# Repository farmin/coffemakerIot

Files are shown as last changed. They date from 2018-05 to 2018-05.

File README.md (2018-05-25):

# mokkamaster-autoff-iot

Simple project to demonstrate howto use Wifi and mqtt on a esp32 using the Arduino
framework. The project includes a custom sensor board that comunicates to host via
i2c. The sensor is ment to provide useful feedback from a MokkaMaster or similar type
of coffe machine.

## Installing

This project uses [Platformio](https://platformio.org/) as build platform. It installs from
terminal by typing in the following commands:
```
pip install platformio
cd ../coffemakerIot
platformio run
platformio run -t upload

```
### Prerequisites

You probably need pip to install platfomrio. you also need to add yourself to the dialout 
group.

```
python pip
sudo adduser $USER dialout
```

## Known bugs

I2c Bus dropouts, could be hw fault.
Wifi dropouts

# Investigate this
[E][ssl_client.cpp:32] handle_error(): UNKNOWN ERROR CODE (004E)
[E][ssl_client.cpp:34] handle_error(): MbedTLS message code: -78
[E][ssl_client.cpp:84] start_ssl_client(): Connect to Server failed!
[E][WiFiClientSecure.cpp:108] connect(): lwip_connect_r: 113
[E][ssl_client.cpp:84] start_ssl_client(): Connect to Server failed!
[E][WiFiClientSecure.cpp:108] connect(): lwip_connect_r: 113
[E][ssl_client.cpp:84] start_ssl_client(): Connect to Server failed!
[E][WiFiClientSecure.cpp:108] connect(): lwip_connect_r: 113

## Built With

* [Arduino](https://www.arduino.cc/) - Arduino enviroment
* [ArduinoJson](https://arduinojson.org/) - Json library
* [arduino-mqtt](https://github.com/256dpi/arduino-mqtt) - Mqtt framework
* [Adafruit-sensors](https://www.adafruit.com/) - libraries for ADS1X15 and MLX90614 sensors

## Authors

* **Armin Bårdseth** - *Initial work*

## License

This project is licensed under the MIT License - see the [LICENSE.md](LICENSE.md) file for details

## Acknowledgments

* Hat tip to anyone who's code was used
* Inspiration
* etc

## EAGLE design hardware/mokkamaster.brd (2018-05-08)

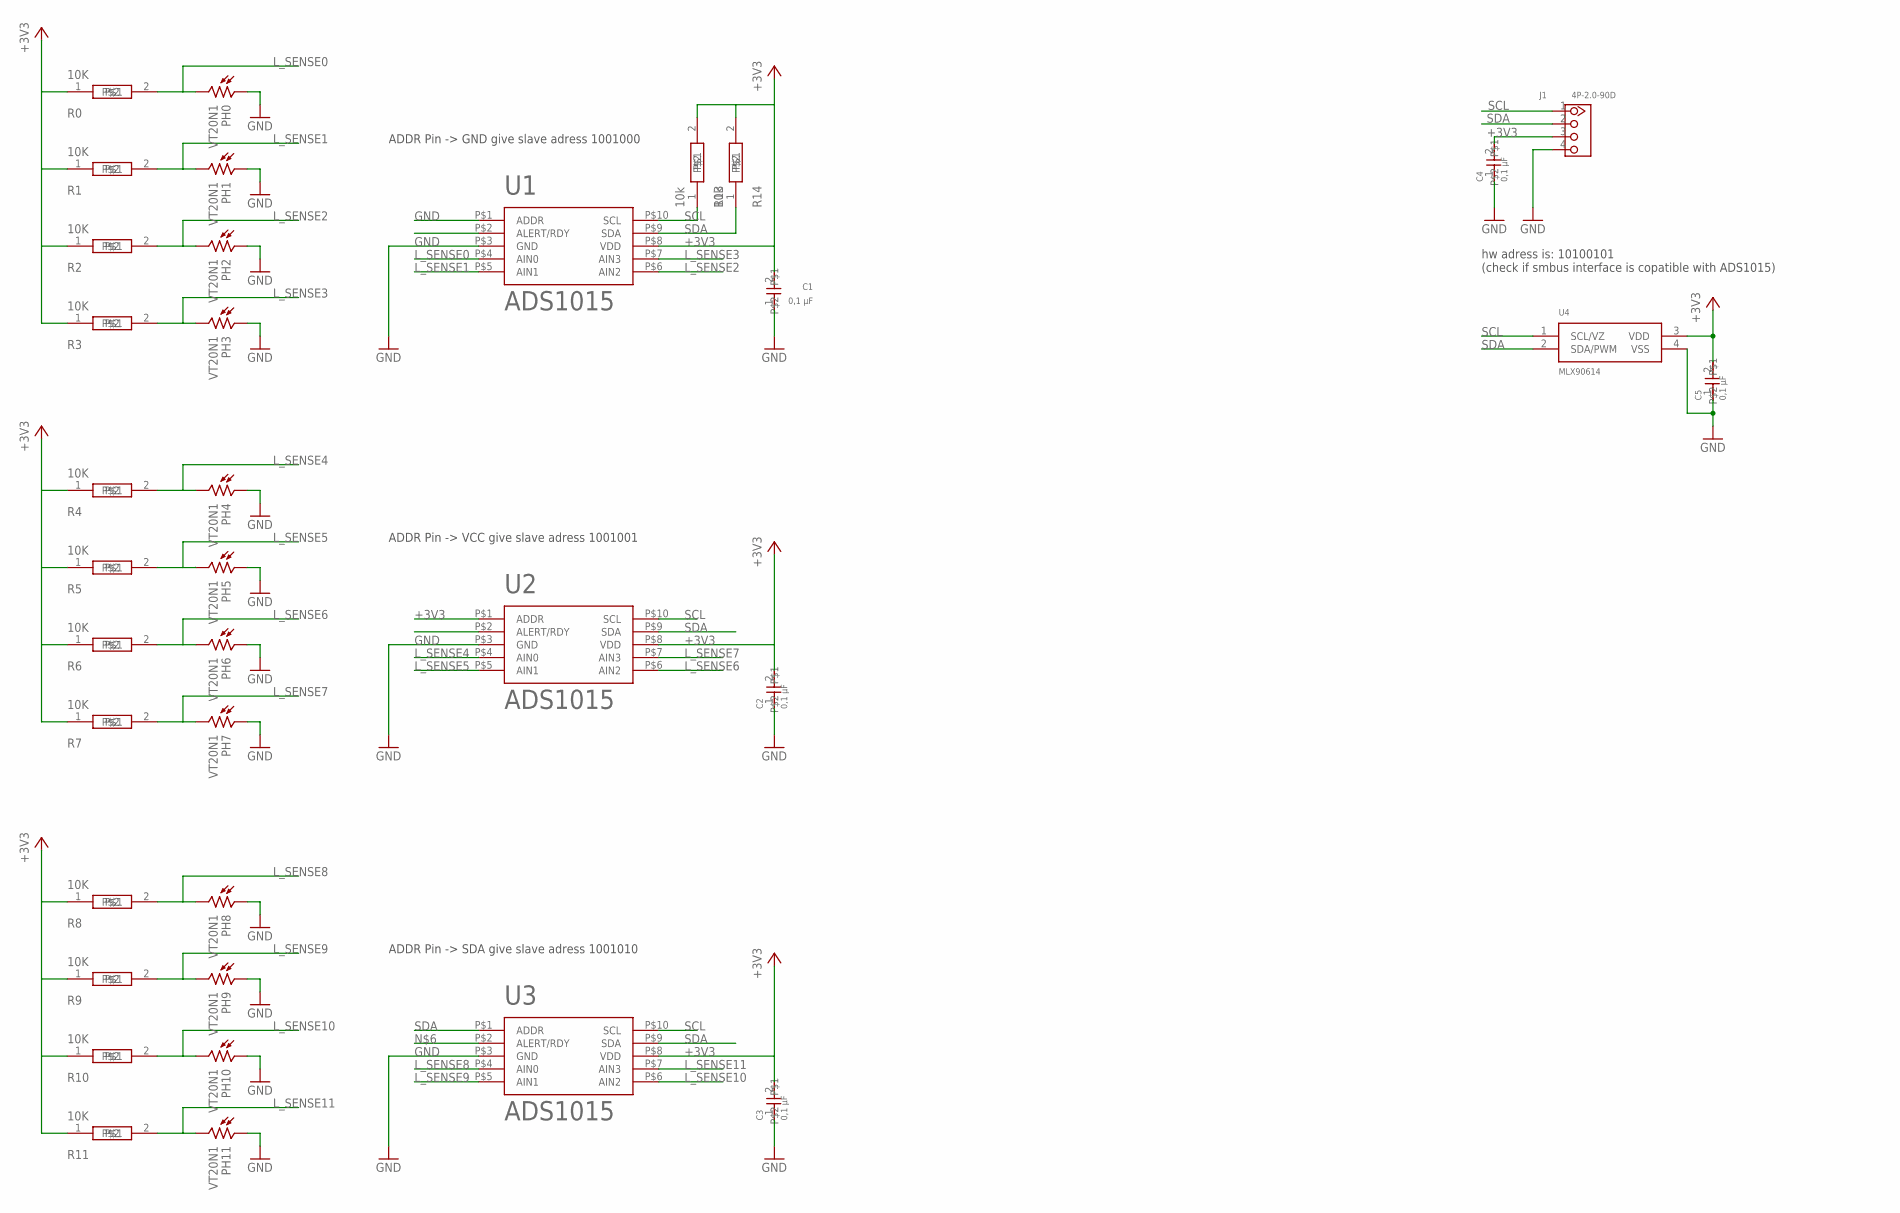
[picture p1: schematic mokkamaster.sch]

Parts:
C1, C2, C3, C4, C5: 0,1 µF; C0603
J1: 4P-2.0-90D; HW4-2.0-90D
PH0, PH1, PH2, PH3, PH4, PH5, PH6, PH7, PH8, PH9, PH10, PH11: VT20N1; TO46-VT200
R0, R1, R2, R3, R4, R5, R6, R7, R8, R9, R10, R11: 10K; R0603
R13, R14: 10k; R0603
U1, U2, U3: ADS1015; PDSO-G10
U4: MLX90614; SPARKFUN_TO-39

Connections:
+3V3: C1.2, C2.2, C3.2, C4.2, C5.2, J1.3, R0.1, R1.1, R2.1, R3.1, R4.1, R5.1, R6.1, R7.1, R8.1, R9.1, R10.1, R11.1, R13.2, R14.2, U1.P$8 (VDD), U2.P$1 (ADDR), U2.P$8 (VDD), U3.P$8 (VDD), U4.3 (VDD)
GND: C1.1, C2.1, C3.1, C4.1, C5.1, J1.4, PH0.1, PH1.1, PH2.1, PH3.1, PH4.1, PH5.1, PH6.1, PH7.1, PH8.1, PH9.1, PH10.1, PH11.1, U1.P$1 (ADDR), U1.P$3 (GND), U2.P$3 (GND), U3.P$3 (GND), U4.4 (VSS)
L_SENSE0: PH0.2, R0.2, U1.P$4 (AIN0)
L_SENSE1: PH1.2, R1.2, U1.P$5 (AIN1)
L_SENSE2: PH2.2, R2.2, U1.P$6 (AIN2)
L_SENSE3: PH3.2, R3.2, U1.P$7 (AIN3)
L_SENSE4: PH4.2, R4.2, U2.P$4 (AIN0)
L_SENSE5: PH5.2, R5.2, U2.P$5 (AIN1)
L_SENSE6: PH6.2, R6.2, U2.P$6 (AIN2)
L_SENSE7: PH7.2, R7.2, U2.P$7 (AIN3)
L_SENSE8: PH8.2, R8.2, U3.P$4 (AIN0)
L_SENSE9: PH9.2, R9.2, U3.P$5 (AIN1)
L_SENSE10: PH10.2, R10.2, U3.P$6 (AIN2)
L_SENSE11: PH11.2, R11.2, U3.P$7 (AIN3)
SCL: J1.1, R13.1, U1.P$10 (SCL), U2.P$10 (SCL), U3.P$10 (SCL), U4.1 (SCL/VZ)
SDA: J1.2, R14.1, U1.P$9 (SDA), U2.P$9 (SDA), U3.P$1 (ADDR), U3.P$9 (SDA), U4.2 (SDA/PWM)

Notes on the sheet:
ADDR Pin -> GND give slave adress 1001000
ADDR Pin -> VCC give slave adress 1001001
ADDR Pin -> SDA give slave adress 1001010
hw adress is: 10100101 (check if smbus interface is copatible with ADS1015)

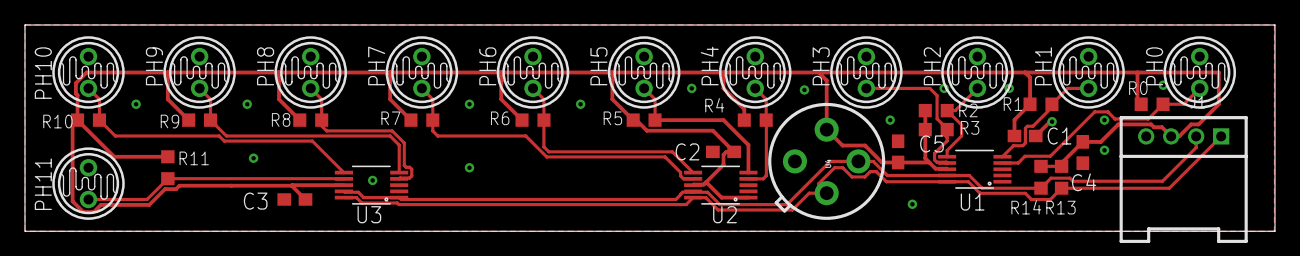
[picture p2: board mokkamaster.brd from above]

Board: 2 copper layers, 100.0 x 16.5 mm, 36 parts (0 on the bottom side), 16 nets.

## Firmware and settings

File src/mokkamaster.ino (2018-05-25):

// Simple Demonstration of a coffe level and temperature sensor. Sends
// mqtt data to broker via Wifi.

// based on a example by Joël Gähwiler
// https://github.com/256dpi/arduino-mqtt

//bugs: See README.md , Wifi droputs, i2c bus error.

#include <Arduino.h>
#include "EEPROM.h"
#include <ArduinoJson.h>
#include <WiFiClientSecure.h>
#include <MQTT.h>
#include <Adafruit_ADS1015.h>
#include <Adafruit_MLX90614.h>


// i2c sensors initialisation. Ads0-2 is light sensors
// and mlx is ir temperature sensor.
Adafruit_ADS1115 ads0(0x48); // address 0b1001000
Adafruit_ADS1115 ads1(0x49); // address 0b1001001
Adafruit_ADS1115 ads2(0x4a); // address 0b1001010
Adafruit_MLX90614 mlx = Adafruit_MLX90614(); // address 5A 

// Constants for wifi connection.
const char ssid[] = SSID_NAME;
const char pass[] = SSID_PASWORD;

WiFiClientSecure net;
MQTTClient client;
unsigned long lastMillis = 0;

// Json buffer constants
StaticJsonBuffer<256> jb;
JsonObject &obj = jb.createObject();
char output[128];

// Defines Button and led pins
const int buttonPin = 23;
const int buttonDrivePin = 12;
//const int ledPin = 13;

// variables for intterupts
volatile int interruptCounter;
int timeSincePowerSwitchToggle;

hw_timer_t * timer = NULL;
portMUX_TYPE timerMux = portMUX_INITIALIZER_UNLOCKED;

// Includes all data from the sensor stick
enum states{
    idle,
    filling,
    hotplate,
    cooling
};
struct SensorLevelArray{
    unsigned int fillLevel = 0;
    double tempObjectC = 0;
    double tempAmbientC = 0;
    const static int thresholdNum = 12;
    unsigned int sensor[thresholdNum];
    unsigned int sensorThresholdValues[thresholdNum];
    unsigned int currentSense = 0;
    int powerTimer = 0;
    states machineState;
};
SensorLevelArray fillArray;

// EEPROM/Flash store size. Determine number of bytes needed to
// store reference values.
#define EEPROM_SIZE fillArray.thresholdNum * sizeof(unsigned int) // <- fix constant
// pin for current reading with ADC conversion.
#define ANALOG_PIN_0 35 

// Used for debugging.
// #define DEBUG 
#ifdef DEBUG
    #define DEBUG_PRINT(x)      Serial.print (x)
    #define DEBUG_PRINTln(x)    Serial.println (x)
#else
    #define DEBUG_PRINT(x)
    #define DEBUG_PRINTln(x)
#endif

void IRAM_ATTR powerUsageTimer() {
  portENTER_CRITICAL_ISR(&timerMux);
  interruptCounter++;
  portEXIT_CRITICAL_ISR(&timerMux);

}



// Checks if we have a valid connection for Wifi and
// mqtt broker.
void connect()
{
    #define DEBUG
    // Checks if we got a wifi connection,
    // reboots system if we fails 15 times.
    uint8_t i = 0;
    DEBUG_PRINT("checking wifi...");
    while (WiFi.status() != WL_CONNECTED) {
	DEBUG_PRINT(".");
	delay(1000);
	i++;
	if (i > 15){
	    // restart when wifi hangs
	    ESP.restart();
	}
    }


    
    // Connects to mqtt broker, hangs if none is
    // found.
    DEBUG_PRINT("\n\rconnecting...");
    while (!client.connect("mokkamaster", "try", "try")) {
	DEBUG_PRINT(".");
	delay(1000);
    }
    DEBUG_PRINTln("\n\rconnected!");
    client.subscribe("coffeMaker1");
    #undef DEBUG
}


// Message received callback. Does nothing
// except printing topics and payload.
void messageReceived(String &topic, String &payload) {
    Serial.println("incoming: " + topic + " - " + payload);
    // client.unsubscribe("coffeMaker1");
}

void setup()
{
    Serial.begin(115200);
    pinMode(buttonPin, INPUT);
    pinMode(buttonDrivePin, OUTPUT);
    digitalWrite(buttonDrivePin, HIGH);

    //start timer
    timer = timerBegin(0, 80, true);
    timerAttachInterrupt(timer, &powerUsageTimer, true);
    timerAlarmWrite(timer, 1000000, true); // every 1 second
    timerAlarmEnable(timer);
    
    if (!EEPROM.begin(EEPROM_SIZE))
    {
	Serial.println("failed to initialise EEPROM");
	delay(1000000);
    }
    //    for (int i = 0; i < EEPROM_SIZE; ++i)
    for (int i = 0; i < fillArray.thresholdNum ; i++)
    {
	Serial.print("eeprom :" + String(i) + " : ");
	Serial.println(EEPROM.readUInt(i*4));
	
    }
    // initialize i2c bus and sensors.
    ads0.begin();
    ads1.begin();
    ads2.begin();
    mlx.begin();

    // starts Wifi connection.
    WiFi.begin(ssid, pass);
    
    // MQTT brokers usually use port 8883 for secure connections.
    //client.begin("broker.shiftr.io", 8883, net);
    client.begin("192.168.188.235", 8883, net);
    //client.begin("mqtt.googleapis.com", 8883, net);
    client.onMessage(messageReceived);
    connect();
}

// Loops trough i2c adc, and updates values
// in struct sensorArray
int getSensorData(SensorLevelArray *sensorArray){
    for (uint8_t i = 0; i != sensorArray->thresholdNum ; i++ ){
	if (i >= 0 && i <= 3){
	    sensorArray->sensor[i] = ads0.readADC_SingleEnded(i);
	}
	else if( i >= 3  && i <= 7 ){
	    sensorArray->sensor[i] = ads1.readADC_SingleEnded(i - 4);
	}
	else if (i >= 7 ){
	    sensorArray->sensor[i] = ads2.readADC_SingleEnded(i - 8);
	}
	else{
	    Serial.print("error");
	}
    }
}

// Updates threshold values stored in EEPROM/FLASH. Theese
// Are used when we determine fill level. ButtonPin is used when we
// store settings.
void configMode(SensorLevelArray *sensorArray){
    // <=TODO give some visulal feedback when user isn't connected via terminal.
    // <=TODO fix fix hang forever, if user dosent complete setup.
    int serialByte = 0;
    Serial.println("This is for configuring you brand new coffee machine iot sensor.");
    Serial.println("Please place a empty coffe container on the hotplate and press");
    Serial.println("button.");
    delay(1000);
    while( digitalRead(buttonPin) != HIGH)
    {
	Serial.print('.');
	delay(250);
    }
    SensorLevelArray sensorsEmptyContainer;
    getSensorData(&sensorsEmptyContainer);
    Serial.println("Now fill the container with coffe and press the button again");
    delay(1000);
    while( digitalRead(buttonPin) != HIGH)
    {
	Serial.print('.');
	delay(250);
    }
    unsigned int cf = 0;
    SensorLevelArray sensorsWhenCoffe;
    getSensorData(&sensorsWhenCoffe);
    for(int i = 0; i < sensorArray->thresholdNum ; i++ )
    {
	// dLow + dHigh / 2
	cf = ((sensorsEmptyContainer.sensor[i] + sensorsWhenCoffe.sensor[i])) ;
	cf = cf / 2 ;
	sensorArray->sensorThresholdValues[i] = cf;
    }
}


// main program loop
void loop() {

    if(interruptCounter > 0) {
    	portENTER_CRITICAL(&timerMux);
    	interruptCounter--;
    	portEXIT_CRITICAL(&timerMux);
    	timeSincePowerSwitchToggle++;
    	DEBUG_PRINT("interrupt occured ");
    	DEBUG_PRINTln(timeSincePowerSwitchToggle);
    }
    
    delay(200);
    if(digitalRead(buttonPin) == HIGH){
	configMode(&fillArray);
	for( int i = 0; i != 12; ++i){
	    EEPROM.writeUInt(i * sizeof(fillArray.sensorThresholdValues[i]),  fillArray.sensorThresholdValues[i]);
	    EEPROM.commit();
	}
    }

    client.loop();
    delay(1000);  // <- should fix some issues with WiFi stability
    if (!client.connected()){
	connect();
	DEBUG_PRINT(":");
    }
    //
    //Only runs when millis overflows.
    //This is our main loop.
    if (millis() - lastMillis > 2000) {
	delay(10);
	for( int i = 0; i < fillArray.thresholdNum ; ++i){
	    DEBUG_PRINT("eeprom :" + String(i) + " : ");
	    DEBUG_PRINTln(EEPROM.readUInt(i* sizeof(fillArray.sensorThresholdValues[i])));
	}
	// Checks if coffemaker draws current
	fillArray.currentSense = analogRead(ANALOG_PIN_0); // this needs a filter or something
	if(fillArray.currentSense > 2000){ //half adc max valeu
	    fillArray.machineState = idle;
	}
	// need a better filter for better resolution
	// no fillarray.machineState == hotplate
	else{
	    fillArray.machineState = idle;
	}
	// DEBUG_PRINTln(currentSense);
	fillArray.currentSense = analogRead(ANALOG_PIN_0); // this needs a filter or something
	getSensorData(&fillArray);
	//getCoffeLevel(&fillArray);
	fillArray.tempObjectC =  mlx.readObjectTempC();
	fillArray.tempAmbientC = mlx.readAmbientTempC();
	//
	// Compares sensorvalue with reference value and sets coffeLevel count accordingly.
	int coffeLevel = 0;
	int i = 0;
	for( sensorValue : fillArray.sensor){
	    if (sensorValue > fillArray.sensorThresholdValues[i]){ coffeLevel++ ;}
	    i++;
	}
	fillArray.fillLevel = coffeLevel;
	fillArray.powerTimer= timeSincePowerSwitchToggle;
	//Updates Jsonbuffer with current values
	//and sends mqtt message
	obj["powerTimer"] = fillArray.powerTimer;
	obj["currentSense"] = fillArray.currentSense;
	obj["CoffeLevel"] = fillArray.fillLevel;
	obj["machineState"] = fillArray.machineState;
	obj["coffeTemp"].set(fillArray.tempObjectC);
	obj["ambientTemp"].set(fillArray.tempAmbientC);
	obj.printTo(output);
	Serial.println(output);
	client.publish("coffeMaker1", output);

	lastMillis = millis();
    }
}

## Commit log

2018-05-08 added shematic
    [mokkamaster.brd, mokkamaster.sch]
2018-05-14 started on calibration
2018-05-25 Added some documentation, code cleaning. some changes to current sense
